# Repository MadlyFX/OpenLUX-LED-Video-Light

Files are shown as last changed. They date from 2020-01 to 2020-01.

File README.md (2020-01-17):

# OpenLUX LED Film Light
 
The OpenLUX Light is a high-CRI, flicker-free, bicolor LED light intended for film and video use. It's small enough to fit in a Bowens mount flash adaptor, letting it accept accessories like soft boxes and reflectors. 

Fusion 360 Assembly: https://a360.co/2Nx0XiO

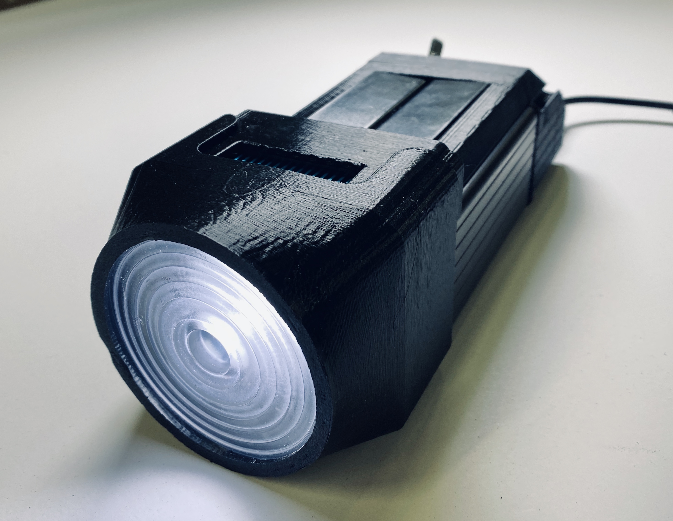
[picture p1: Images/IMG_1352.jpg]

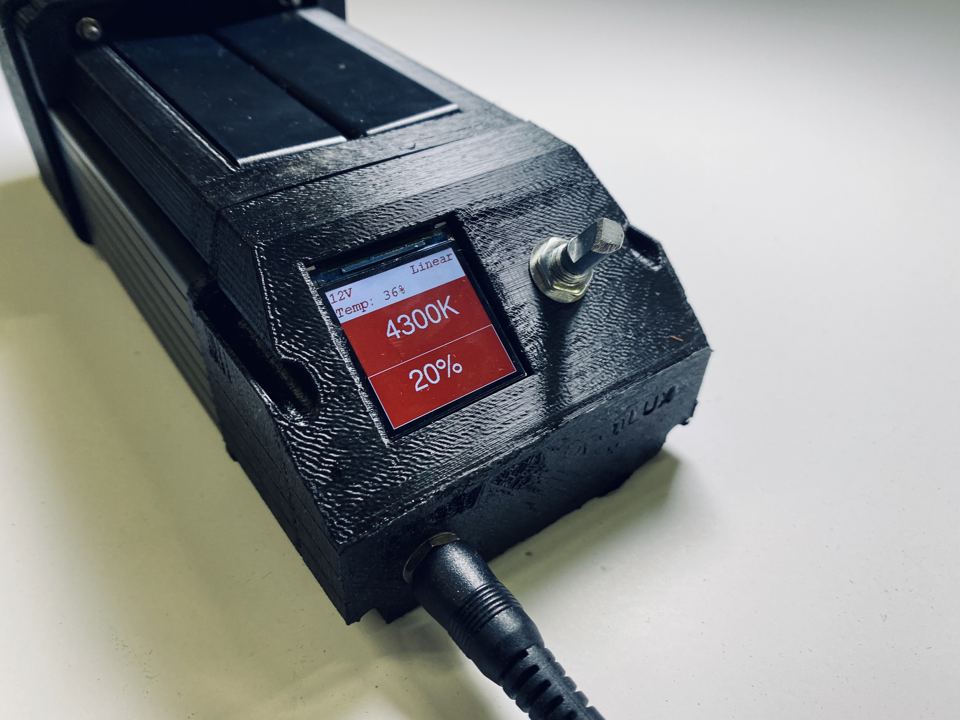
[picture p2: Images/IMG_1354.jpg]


The light features a CTM-22 COB LED module.

###### Features:

 - Bowens mount compatible
 - Accepts small fresnel lenses
 - Full Color LCD Display Menu
 - Overtemp Protection
 - 8Khz PWM Rate (Can be increased to 10Khz)
 - Runs Arduino Code
 
 ###### Specs:
 
  - 2700K-6500K Adjustable Color Temp
  - 95CRI Average
  - 150 Lux @20ft w/ medium lens (100% brightness, 4700K temp, Turbo Mode)
  - 9-28V input
  - 3 amps max for linear dimming, 6 amps max for Turbo mode
  
  ## Cost and Assembly

The light can be made for around $150 and can easily be built in about 3 or 4 hours. It uses an aluminum enclosure as the main body, augmented with 3D printed sections. There is a custom front bezel that needs to be lasercut at a place like Oshcut or SendCutSend, out of .200 aluminum, which costs about $35.

An assembly guide can be found here: https://www.madlyfx.com/openlux-assembly-notes/

## Electronics

The main PCB uses a Teensy microcontroller board to control everything. It's programmed in Arduino, and features a basic menu to control the brightness, color temp, and a long press will switch between Linear and Turbo dimming.

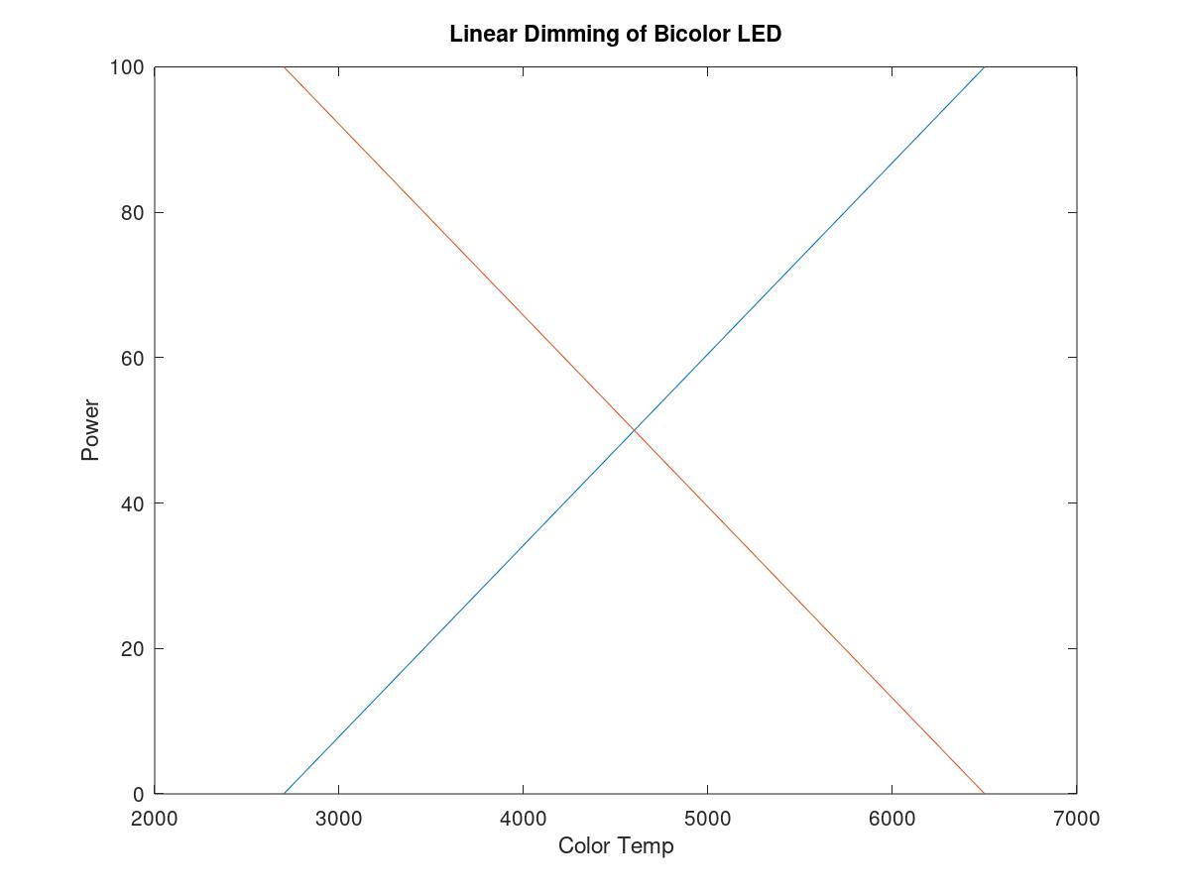
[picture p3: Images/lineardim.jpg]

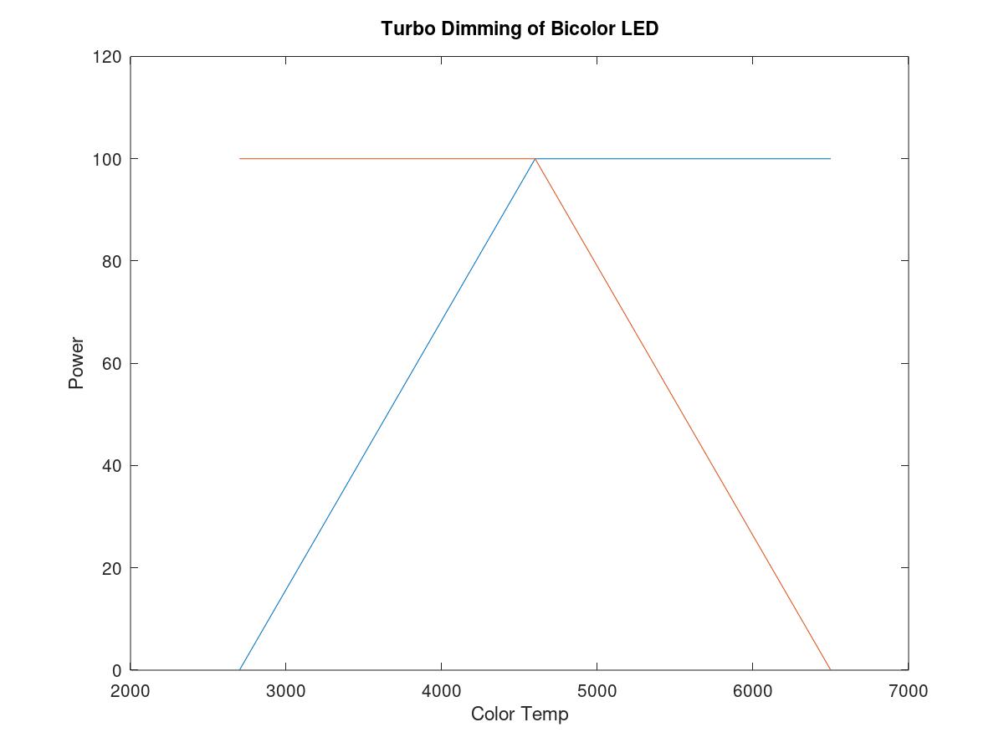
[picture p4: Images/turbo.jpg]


The Teensy was chosen for the performance overhead, which allows future addition of features like effects, DMX, and even fun stuff like imitating the Oribiter's color matching feature. The PCB was desined to be simple to understand and easy to solder, using all through-hole components and a monolithic regulator.

The fixure draws 3A max in the Linear dimming mode, and 6A in the turbo mode.

## Performance

Up to 150 lux at 20 feet can be achieved, making it plenty bright enough for general purpose use. However, it should be noted that with the Silent fan, the light will only last about 60 seconds before overheating at 4600K, 100%, Turbo dimming. Sticking with the Linear dimming mode will provide much longer runtimes. If the light overheats, it will turn off and lock itself out, requiring a restart.

## Mechanical

The light can fit into a Bowens mount holder for camera flashes, which allows it to be attached to a stand and accept things like softboxes. https://www.amazon.com/gp/product/B00JS3MINC/ref=ppx_yo_dt_b_search_asin_title?ie=UTF8&psc=1

The front section takes Molly Fresnel lenses from Ledil, and allows a certain amount of adjustability. Ledil makes three of these lenses in different focal lengths, but the wide 60 degree one has the same beam angle as a typical fresnel lamp at full flood. 

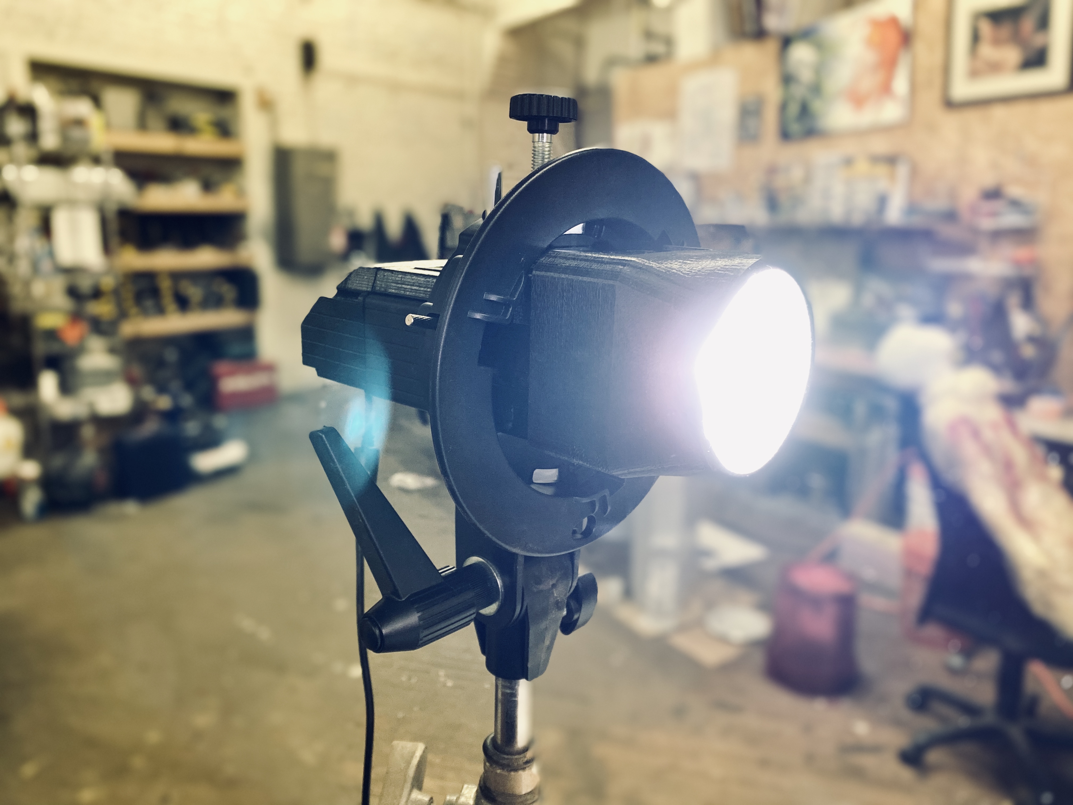
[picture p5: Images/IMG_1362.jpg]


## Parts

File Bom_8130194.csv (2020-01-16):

Manufacturer Part Number | Manufacturer | Digi-Key Part Number | Customer Reference | Reference Designator | Packaging | Quantity | Unit Price | Extended Price | Description
LDH-45A-1050W | MEAN WELL USA Inc. | 1866-5295-ND | LED Drivers |  | Tray | 2 | 12.10000 | $24.20 | LED DRVR CC BOOST 12-43V 1.05A
RNF18FTD10K0 | Stackpole Electronics Inc | RNF18FTD10K0CT-ND |  |  | Cut Tape (CT) | 1 | 0.10000 | $0.10 | RES 10K OHM 1/8W 1% AXIAL
RNF18FTD15K0 | Stackpole Electronics Inc | RNF18FTD15K0CT-ND |  |  | Cut Tape (CT) | 1 | 0.10000 | $0.10 | RES 15K OHM 1/8W 1% AXIAL
RNF18FTD1K87 | Stackpole Electronics Inc | RNF18FTD1K87CT-ND |  |  | Cut Tape (CT) | 1 | 0.10000 | $0.10 | RES 1.87K OHM 1/8W 1% AXIAL
R-78E5.0-0.5 | Recom Power | 945-1648-5-ND | 5V Regulator |  | Tube | 1 | 2.70000 | $2.70 | DC DC CONVERTER 5V 3W
ATS-FPS058061023-42-C2-R0 | Advanced Thermal Solutions Inc. | ATS1623-ND | Heatsink |  | Bulk | 1 | 7.51000 | $7.51 | HEATSINK 57.9X60.96X22.86MM FP
CTM-22-6527-90-36-TW01 | Luminus Devices Inc. | 1214-1553-ND | LED |  | Tray | 1 | 18.38000 | $18.38 | LED COB CTM22 WHITE
HA60151V4-1000U-A99 | Sunon Fans | 259-1792-ND | Silent Fan |  | Bulk | 1 | 5.98000 | $5.98 | 60X60X15 12VDC VAPO 12.7CFM
612F/2 | ebm-papst Inc. | 381-3281-ND | Performance Fan |  | Bulk | 1 | 20.22000 | $20.22 | FAN AXIAL 60X15MM 12VDC
1455K1201BK | Hammond Manufacturing | HM1498-ND | Enclosure |  | Bulk | 1 | 20.66000 | $20.66 | BOX ALUM BLACK 4.72"L X 3.07"W
C15801_MOLLY-M | Ledil | 711-1422-ND | Medium Lens |  | Tray | 1 | 10.28000 | $10.28 | LENS CLEAR 36DEG MEDIUM
C15802_MOLLY-W | Ledil | 711-1423-ND | Wide Lens |  | Tray | 1 | 10.28000 | $10.28 | LENS CLR 61DEG FRESNEL RING TWST
92095A474 |  |  | Heatsink Screws | McMaster Carr
90695A033 |  |  | Heatsink Nuts | McMaster Carr
90087A148 | TubeDepot | 2197-90087A148-ND | End Panel Screws |  | Bulk | 4 | 0.18000 | $0.72 | 632 PAN HEAD SELF TAP SCREW 1/2
EN11-HSM1AF15 | TT Electronics/BI | 987-1188-ND | Rotary Encoder |  | Tray | 1 | 1.25000 | $1.25 | ROTARY ENCODER MECHANICAL 20PPR
https://www.amazon.com/dp/B07P9X3L7M/ref=cm_sw_em_r_mt_dp_U_wY8hEbDQX069W |  |  | LCD Screen | Amazon
90087A106 | TubeDepot | 2197-90087A106-ND | PCB Retention Screw |  | Bulk | 1 | 0.16000 | $0.16 | 440 PAN HEAD SELF TAP SCREW 1/4
B57863S0103F040 | TDK Electronics Inc. | 495-2149-ND | Thermistor |  | Bulk | 1 | 3.97000 | $3.97 | THERMISTOR NTC 10KOHM 3988K BEAD
91225A040 |  |  | Thermistor Washer | McMaster Carr
2756 | Adafruit Industries LLC | 1528-2385-ND | Teensy 3.2 |  | Bulk | 1 | 24.94000 | $24.94 | TEENSY 3.2 K20 EVAL BRD
1984617 | Phoenix Contact | 277-1721-ND | Screw Terminals |  | Box | 4 | 0.48000 | $1.92 | TERM BLK 2POS SIDE ENT 3.5MM PCB
PJ-005A | CUI Devices | CP-5-ND |  |  | Bag | 1 | 2.11000 | $2.11 | CONN PWR JACK 2X5.5MM SOLDER

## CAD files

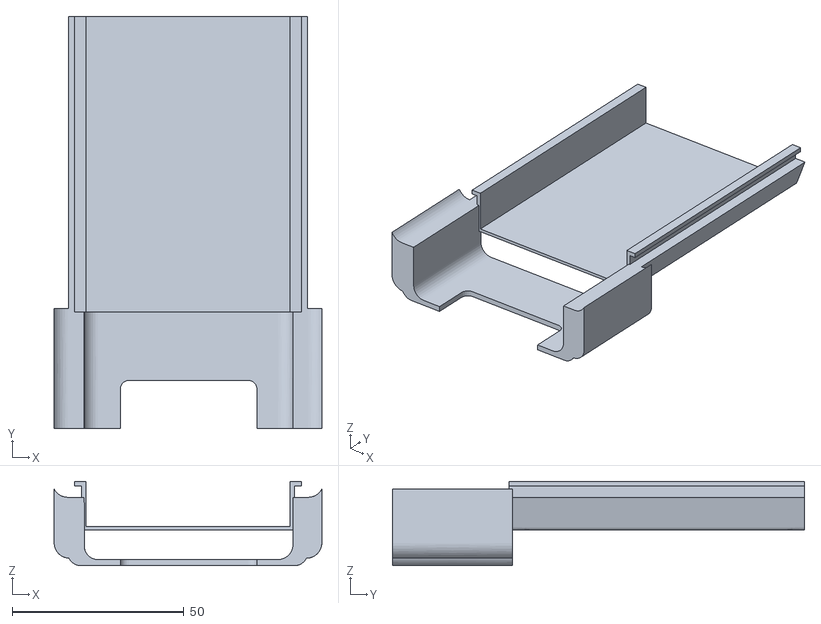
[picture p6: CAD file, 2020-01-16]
3DPrints/Top.stl
78.0 x 120.0 x 24.6

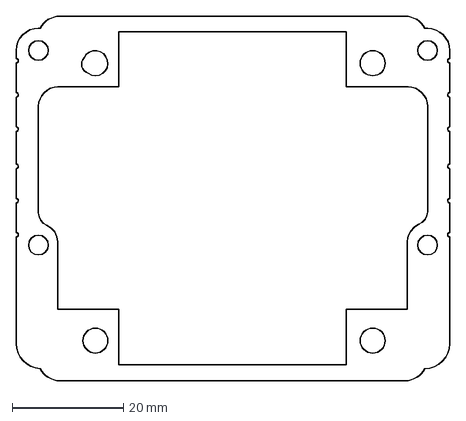
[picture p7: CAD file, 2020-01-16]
Physical/FrontBezel.dxf
78.0 x 65.6 mm

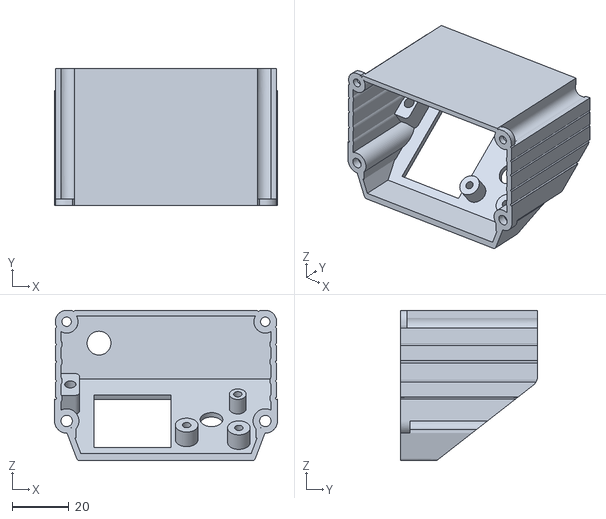
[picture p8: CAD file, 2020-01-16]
3DPrints/Back.stl
78.6 x 48.3 x 53.0

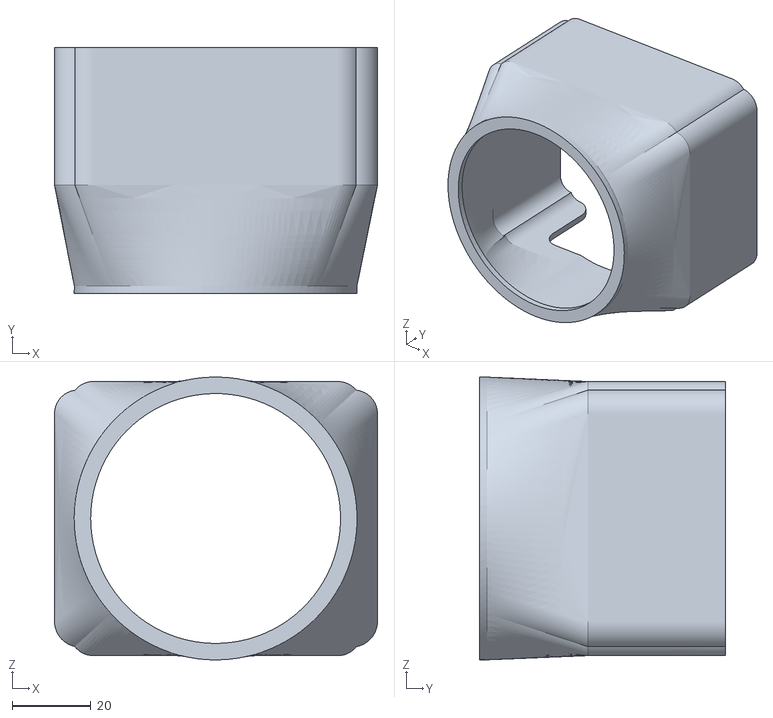
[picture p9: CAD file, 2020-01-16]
3DPrints/FresnelHolder.stl
82.0 x 62.5 x 71.8

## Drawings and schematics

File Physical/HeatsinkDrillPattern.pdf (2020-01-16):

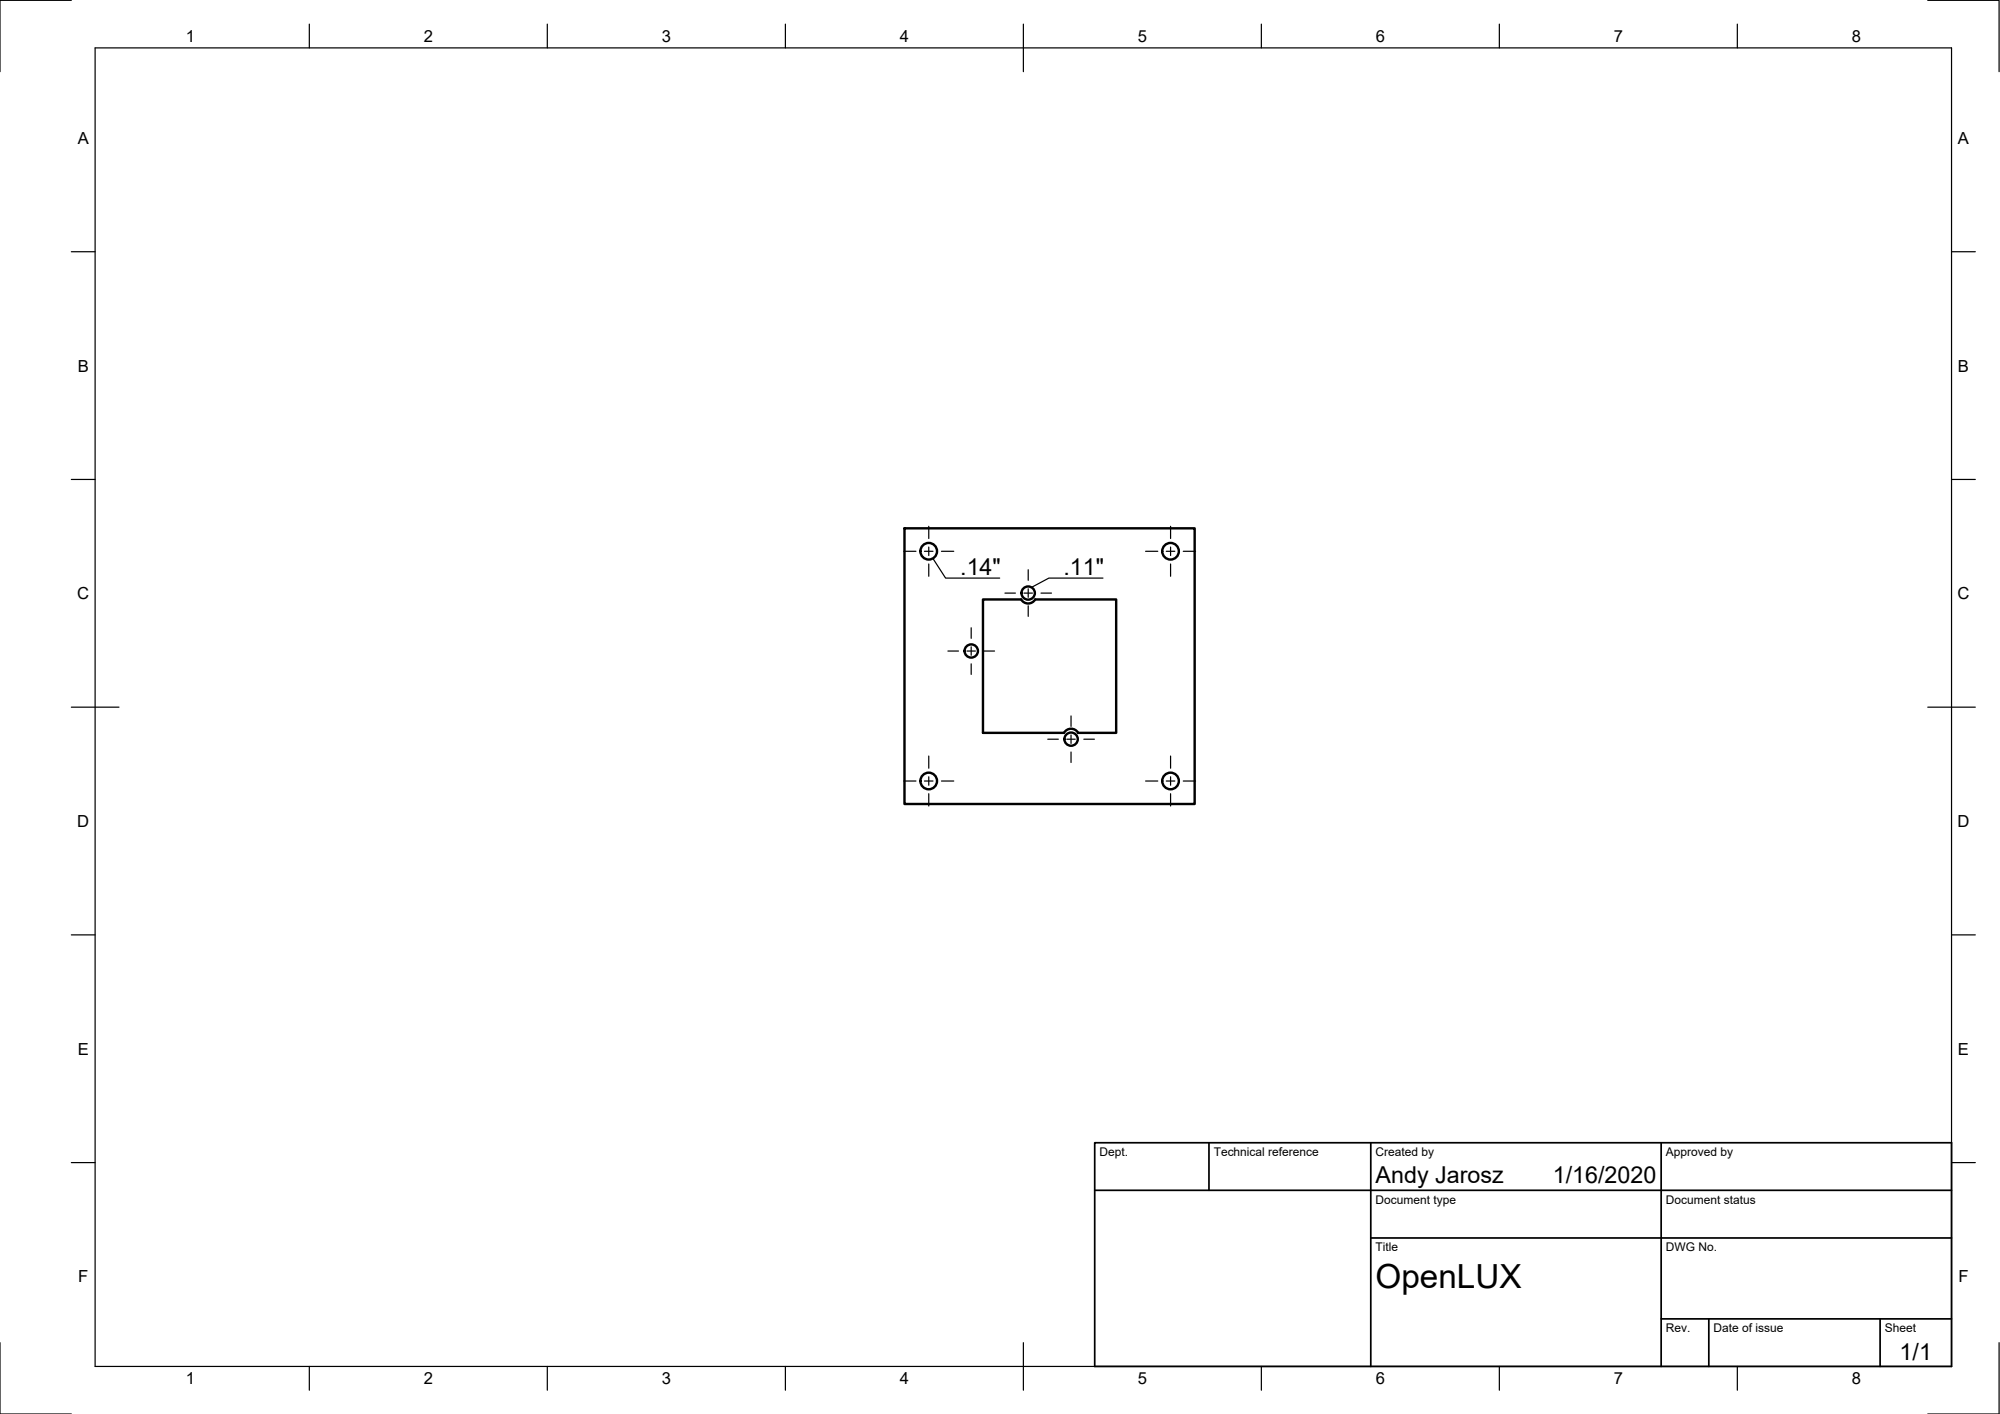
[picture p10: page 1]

Dept. | Technical reference | Created by Andy Jarosz 1/16/2020 | Approved by

Document type | Document status

Title OpenLUX | DWG No.

Rev. | Date of issue | Sheet 1/1

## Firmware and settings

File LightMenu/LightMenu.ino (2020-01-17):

//Code for OpenLUX LED Video Light
//Written by Andy Jarosz

//Third party libraries used:
//AceButton
//Adafruit GFX
//Adafruit ST77
//TeensyEncoder

//The B25 value for the Thermistor will change if you use one other than is in the BOM. Be sure to look up the values for your thermistor, or the temp readings will be thrown off. 

#include <AceButton.h>
using namespace ace_button;

// The pin number attached to the button.
const int BUTTON_PIN = 7;

#include <Adafruit_GFX.h>    // Core graphics library
#include <Adafruit_ST7735.h> // Hardware-specific library for ST7735
#include <Adafruit_ST7789.h> // Hardware-specific library for ST7789
#include <SPI.h>
#include <Fonts/FreeMonoBoldOblique12pt7b.h>
#include <Fonts/FreeSans24pt7b.h>
#include <Encoder.h>

bool powerSelect = true;

bool turboMode = false;

AceButton button(BUTTON_PIN);
void handleEvent(AceButton*, uint8_t, uint8_t);

// which analog pin to connect
#define THERMISTORPIN A7
// resistance at 25 degrees C
#define THERMISTORNOMINAL 10000
// temp. for nominal resistance (almost always 25 C)
#define TEMPERATURENOMINAL 25
// The beta coefficient of the thermistor (usually 3000-4000)
#define BCOEFFICIENT 3988
// the value of the 'other' resistor
#define SERIESRESISTOR 10000
float steinhart;
// For the breakout board, you can use any 2 or 3 pins.
// These pins will also work for the 1.8" TFT shield.
#define TFT_CS        8
#define TFT_RST        9 // Or set to -1 and connect to Arduino RESET pin
#define TFT_DC         10

float value2700;
float value6500;

int currentEncoderPos;

// For 1.3", 1.54", and 2.0" TFT with ST7789:
Adafruit_ST7789 tft = Adafruit_ST7789(TFT_CS, TFT_DC, TFT_RST);

Encoder myEnc(4, 6);

float p = 3.1415926;
long oldPosition  = -999;

int power = 100;
int temp = 2700;

float powerMultiplier;

#define MENU1Y 60
#define MENU1WIDTH 240
#define MENU1HEIGHT 90

#define MENU2Y 150
#define MENU2WIDTH 240
#define MENU2HEIGHT 90

#define MENU1TEXTY 110
#define MENU2TEXTY 200



void setup(void) {
  analogWriteFrequency(23, 8000); //Set 8KHz Pwm Rate
  analogWriteFrequency(22, 8000);
  Serial.begin(9600);
  pinMode(7, INPUT_PULLUP); //Encoder Pullup
  tft.setFont(&FreeSans24pt7b);
  Serial.print(F("Hello! ST77xx TFT Test"));


  // OR use this initializer (uncomment) if using a 2.0" 320x240 TFT:
  tft.init(240, 240, SPI_MODE2);           // Init ST7789 320x240

  Serial.println(F("Initialized"));

  uint16_t time = millis();
  tft.fillScreen(ST77XX_BLACK);
  time = millis() - time;


  // Configure the ButtonConfig with the event handler, and enable all higher
  // level events.
  ButtonConfig* buttonConfig = button.getButtonConfig();
  buttonConfig->setEventHandler(handleEvent);
  buttonConfig->setFeature(ButtonConfig::kFeatureClick);
  buttonConfig->setFeature(ButtonConfig::kFeatureLongPress);



  tft.fillRect(0, 0, 240, 250, ST77XX_RED);

  tft.setCursor(60, 80);
  tft.setTextColor(ST77XX_WHITE);
  tft.setTextWrap(true);
  tft.print("2700K");

  tft.setCursor(60, 200);
  tft.print("100%");

  tft.drawRect(0, MENU1Y, MENU1WIDTH, MENU1HEIGHT, ST77XX_WHITE);

  writeTop();

}

void loop() {

  button.check();

  if (powerSelect == true) {

    if (myEnc.read() > 100) {
      setEnc(100);
    }

    if (myEnc.read() < 0) {
      setEnc(0);
    }

    tft.drawRect(0, 0, 240, 120, ST77XX_RED);
    tft.drawRect(0, MENU2Y, MENU2WIDTH, MENU2HEIGHT, ST77XX_WHITE);
    long newPosition = myEnc.read();
    if (newPosition != oldPosition) {
      oldPosition = newPosition;
      tft.setFont(&FreeSans24pt7b);
      tft.setTextColor(ST77XX_WHITE);
      power = constrain(newPosition, 0, 100);
      tft.fillRect(0, 120, 240, 120, ST77XX_RED);
      tft.setCursor(60, MENU2TEXTY);
      tft.print(power);
      tft.print("%");


      tft.fillRect(0, 0, 240, 120, ST77XX_RED);
      if (turboMode == true) {
        tft.setCursor(10, MENU1TEXTY);
        tft.print("~");
      }
      tft.setCursor(60, MENU1TEXTY);
      tft.print(temp);
      tft.print("K");
      writeTop();
    }
  }

  if (powerSelect == false) { //Temp select

    if (myEnc.read() > 6500) {
      setEnc(6500);
    }

    if (myEnc.read() < 2700) {
      setEnc(2700);
    }

    tft.drawRect(0, 120, 240, 120, ST77XX_RED);
    tft.drawRect(0, MENU1Y, MENU1WIDTH, MENU1HEIGHT, ST77XX_WHITE);
    long newPosition = myEnc.read();
    if (newPosition != oldPosition) {

      if (newPosition > oldPosition) {
        temp = temp += 100;
      } else {
        temp = temp -= 100;
      }
      oldPosition = newPosition;
      tft.setFont(&FreeSans24pt7b);
      tft.setTextColor(ST77XX_WHITE);
      // temp = constrain(newPosition, 2700, 6500);


      tft.fillRect(0, 0, 240, 120, ST77XX_RED);
      if (turboMode == true) {
        tft.setCursor(10, MENU1TEXTY);
        tft.print("~");
      }
      tft.setCursor(60, MENU1TEXTY);

      tft.print(temp);
      tft.print("K");

      tft.setCursor(60, MENU2TEXTY);
      tft.print(power);
      tft.print("%");

      writeTop();

    }


  }

  if (turboMode == false) { //Linear dimming mode, standard
    powerMultiplier = map(power, 0, 100, 0, 255); //Convert the 0-100 human value to a 0-255 8-bit value
    value2700 = map(temp, 2700, 6500, 0, powerMultiplier); //Find the % of that value between 2700 and 6500
    value6500 =  map(temp, 2700, 6500, powerMultiplier, 0); //Find the % of that value between 6500 and 2500

    analogWrite(22, value2700);
    analogWrite(23, value6500);
  } else { //Turbo Mode
    powerMultiplier = map(power, 0, 100, 0, 255); //Simple way to do turbo mode, just multiply PWM values by 2. Arduino automatically limits them to 255.
    value6500 =  map(temp, 2700, 6500, powerMultiplier, 0);
    value2700 = map(temp, 2700, 6500, 0, powerMultiplier);
    analogWrite(22, value2700 * 2);
    analogWrite(23, value6500 * 2);
  }

  //Serial.println(value2700);
  //Serial.println(value6500);
      float average = analogRead(THERMISTORPIN);

      average = 1023 / average - 1;
      average = SERIESRESISTOR * average;
      Serial.print("Thermistor resistance "); 
      Serial.println(average);
      
      
      steinhart = average / THERMISTORNOMINAL;     // (R/Ro)
      steinhart = log(steinhart);                  // ln(R/Ro)
      steinhart /= BCOEFFICIENT;                   // 1/B * ln(R/Ro)
      steinhart += 1.0 / (TEMPERATURENOMINAL + 273.15); // + (1/To)
      steinhart = 1.0 / steinhart;                 // Invert
      steinhart -= 273.15;                         // convert to C
      
      Serial.print("Temperature "); 
      Serial.print(steinhart);
      Serial.println(" *C");


  if (millis() % 5000 == 0 ) { //Every 5 seconds, update top and check the temp
    writeTop();
    checkTemp();
  }
}


void setEnc(int num) {
  myEnc.write(num);
}

void writeTop() { //Write the top statusbar section
  tft.setCursor(0, 20);
  tft.fillRect(0, 0, 240, 55, ST77XX_WHITE);
  tft.setTextColor(ST77XX_RED);
  tft.setFont(&FreeMonoBoldOblique12pt7b);
  float voltage = analogRead(10) * (3.3 /1023.0);
  tft.print(voltage * 9);
  tft.print("V");
  tft.setCursor(0, 45);
  tft.print("Temp: ");
  tft.print(round(steinhart / 100 * 100));
  tft.print("%");

  if (turboMode == false) {
    tft.setCursor(150, 20);
    tft.print("Linear");
    tft.setFont(&FreeSans24pt7b);
    tft.setTextColor(ST77XX_WHITE);
    tft.setCursor(10, MENU1TEXTY);
    tft.print("  ");
  } else {
    tft.setCursor(150, 20);
    tft.print("Turbo");
    tft.setFont(&FreeSans24pt7b);
    tft.setTextColor(ST77XX_WHITE);
    tft.setCursor(10, MENU1TEXTY);
    tft.print("~");
  }
}

void checkTemp() {

  if (steinhart > 80) {
    tft.fillRect(0, 0, 240, 240, ST77XX_RED);
    tft.setFont(&FreeSans24pt7b);
    tft.setTextColor(ST77XX_WHITE);
    tft.setCursor(20, 40);
    tft.setFont(&FreeMonoBoldOblique12pt7b);
    tft.print("OVERTEMP");

    while (1) { //Intentional endless loop crash, turn off the LEDs forever
    analogWrite(22, 0);
    analogWrite(23, 0);
    }
  }
}

void handleEvent(AceButton* /* button */, uint8_t eventType,
                 uint8_t buttonState) {

  // Control the LED only for the Pressed and Released events.
  // Notice that if the MCU is rebooted while the button is pressed down, no
  // event is triggered and the LED remains off.
  switch (eventType) {
    case AceButton::kEventClicked:
      powerSelect = !powerSelect;
      tft.fillRect(0, 0, 240, 240, ST77XX_RED);
      if (powerSelect == true) {
        setEnc(power);
      } else {
        setEnc(temp);
      }
      break;
    case AceButton::kEventLongPressed:
      turboMode = !turboMode;
      writeTop();
      break;
  }


}

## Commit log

2020-01-13 Added Eagle Files
    [LightBoard2.brd, LightBoard2.sch]
2020-01-16 Added physical files
    [Back.stl, Bom_8130194.csv, FresnelHolder.stl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]
2020-01-16 Added Gerbers
    [copper_bottom.gbr, copper_top.gbr, drill_1_16.xln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]
2020-01-17 Updated Code
    [copper_bottom.gbr, copper_top.gbr, drill_1_16.xln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]
